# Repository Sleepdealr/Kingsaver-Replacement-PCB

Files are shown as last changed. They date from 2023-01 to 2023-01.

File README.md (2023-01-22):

# Kingsaver Replacement PCB

Replacement PCB for the Kingsaver

This has been prototyped and is confirmed working

<br />This work is licensed under a <a rel="license" href="http://creativecommons.org/licenses/by-nc-sa/4.0/">Creative Commons Attribution-NonCommercial-ShareAlike 4.0 Unported License</a>.

# Production

Production gerbers are zipped in the `Gerbers` folder, with JLC assembly files in the `jlcpcb/assembly` folder

You can get USB connectors off LCSC at <https://lcsc.com/product-detail/USB-Connectors_Jing-Extension-of-the-Electronic-Co-920-462A2021D10102_C46398.html>

Photo of proto:

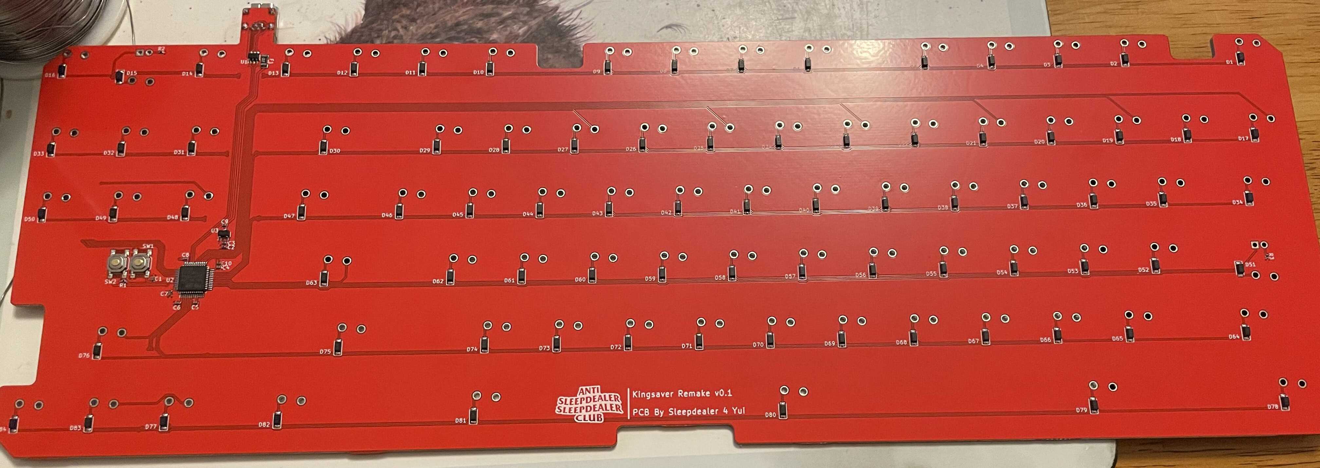
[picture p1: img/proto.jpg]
Photo of proto


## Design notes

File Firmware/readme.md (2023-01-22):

# sleepdealer/kingsaver_redo

sleepdealer/kingsaver_redo

*A short description of the keyboard/project*

* Keyboard Maintainer: [Sleepdealer](https://github.com/Sleepdealr)
* Hardware Supported: *The PCBs, controllers supported*
* Hardware Availability: *Links to where you can find this hardware*

Make example for this keyboard (after setting up your build environment):

    make sleepdealer/kingsaver_redo:default

Flashing example for this keyboard:

    make sleepdealer/kingsaver_redo:default:flash

See the [build environment setup](https://docs.qmk.fm/#/getting_started_build_tools) and the [make instructions](https://docs.qmk.fm/#/getting_started_make_guide) for more information. Brand new to QMK? Start with our [Complete Newbs Guide](https://docs.qmk.fm/#/newbs).

## Bootloader

Enter the bootloader in 3 ways:

* **Bootmagic reset**: Hold down the key at (0,0) in the matrix (usually the top left key or Escape) and plug in the keyboard
* **Physical reset button**: Briefly press the button on the back of the PCB - some may have pads you must short instead
* **Keycode in layout**: Press the key mapped to `RESET` if it is available

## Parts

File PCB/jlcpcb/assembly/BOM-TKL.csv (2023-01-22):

Comment | Designator | Footprint | LCSC
470 | R2,R3 | R_0402_1005Metric | C25117
10k | R1 | R_0402_1005Metric | C25744
USBLC6-2SC6 | U1 | SOT-23-6 | C2827654
100nF | C1,C4,C5,C6,C7,C8 | C_0402_1005Metric | C307331
RST | SW1,SW2 | SW_SPST_SKQG_WithoutStem | C318884
1uF | C10,C2,C3,C9 | C_0402_1005Metric | C52923
XC6206PxxxMR-Regulator_Linear | U3 | SOT-23 | C5446
500mA | F1 | Fuse_1206_3216Metric | C70076
STM32F072C8Tx | U2 | LQFP-48_7x7mm_P0.5mm | C80488
1n4148 | D1,D10,D11,D12,D13,D14,D15,D16,D17,D18,D19,D2,D20,D21,D22,D23,D24,D25,D26,D27,D28,D29,D3,D30,D31,D32,D33,D34,D35,D36,D37,D38,D39,D4,D40,D41,D42,D43,D44,D45,D46,D47,D48,D49,D5,D50,D51,D52,D53,D54,D55,D56,D57,D58,D59,D6,D60,D61,D62,D63,D64,D65,D66,D67,D68,D69,D7,D70,D71,D72,D73,D74,D75,D76,D77,D78,D79,D8,D80,D81,D82,D83,D84,D9 | D_SOD-123-EditSkilk | C81598

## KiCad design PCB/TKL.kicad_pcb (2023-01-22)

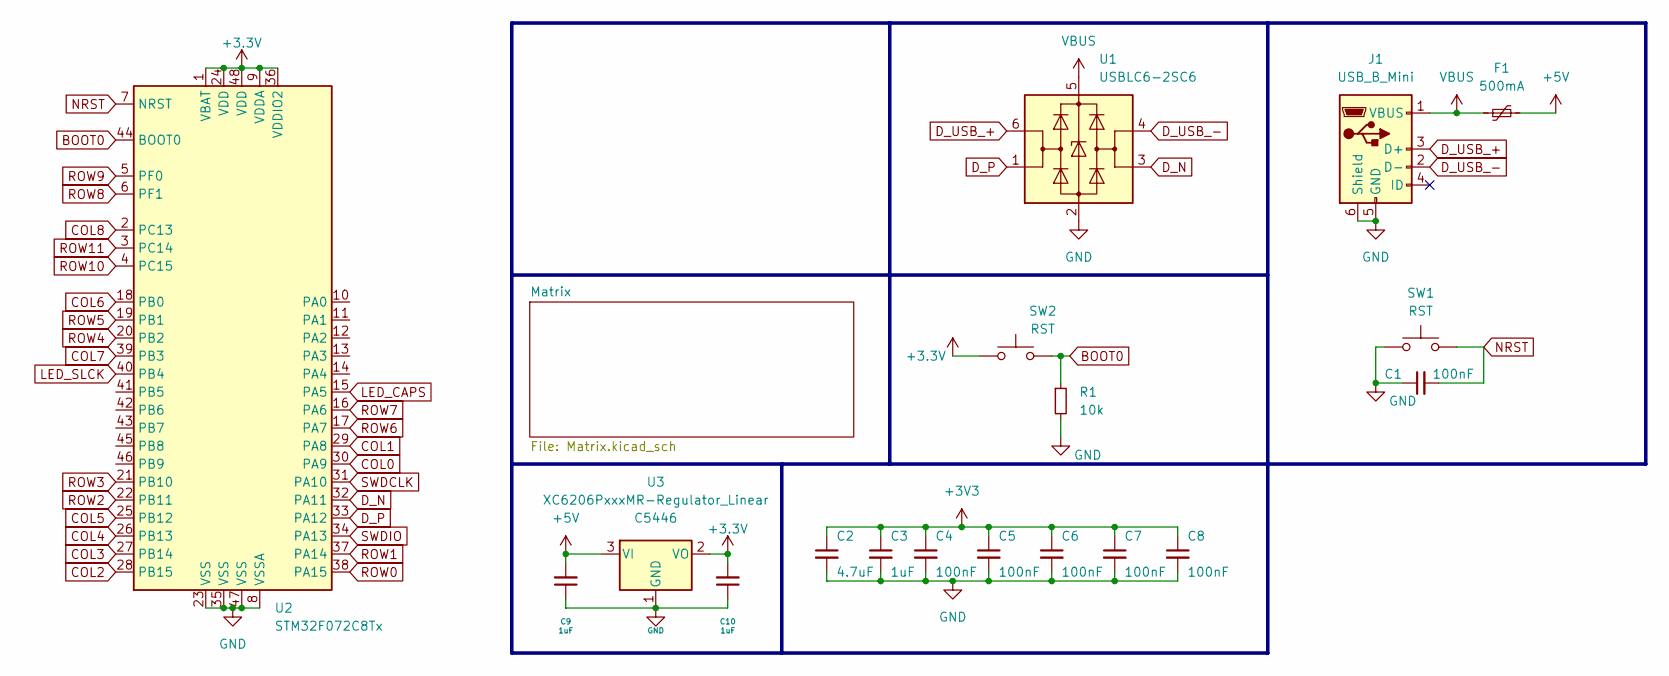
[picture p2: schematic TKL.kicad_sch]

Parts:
C1, C4, C5, C6, C7, C8: 100nF; C_0402_1005Metric; LCSC C307331
C2: 4.7uF; C_0402_1005Metric; LCSC C52923
C3, C9, C10: 1uF; C_0402_1005Metric; LCSC C52923
F1: 500mA; Fuse_1206_3216Metric
J1: USB_B_Mini; USB-Mini-B_ LCSC-C46398; LCSC C105424
R1: 10k; R_0402_1005Metric
SW1, SW2: RST; SW_SPST_SKQG_WithoutStem
U1: USBLC6-2SC6; SOT-23-6
U2: STM32F072C8Tx; LQFP-48_7x7mm_P0.5mm
U3: XC6206PxxxMR-Regulator_Linear; SOT-23; LCSC C5446

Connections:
+5V: C9.2, F1.2, U3.3 (VI)
BOOT0: R1.1, SW2.2, U2.44 (BOOT0)
COL0: U2.30 (PA9); also elsewhere on the board
COL1: U2.29 (PA8); also elsewhere on the board
COL2: U2.28 (PB15); also elsewhere on the board
COL3: U2.27 (PB14); also elsewhere on the board
COL4: U2.26 (PB13); also elsewhere on the board
COL5: U2.25 (PB12); also elsewhere on the board
COL6: U2.18 (PB0); also elsewhere on the board
COL7: U2.39 (PB3); also elsewhere on the board
COL8: U2.2 (PC13); also elsewhere on the board
D_N: U1.3 (I/O2), U2.32 (PA11)
D_P: U1.1 (I/O1), U2.33 (PA12)
D_USB_+: J1.3 (D+), U1.6 (I/O1)
D_USB_-: J1.2 (D-), U1.4 (I/O2)
GND: C1.1, C2.2, C3.2, C4.2, C5.2, C6.2, C7.2, C8.2, C9.1, C10.1, J1.5 (GND), J1.6 (Shield), R1.2, SW1.1, U1.2 (GND), U2.8 (VSSA), U2.23 (VSS), U2.35 (VSS), U2.47 (VSS), U3.1 (GND); also elsewhere on the board
LED_CAPS: U2.15 (PA5); also elsewhere on the board
LED_SLCK: U2.40 (PB4); also elsewhere on the board
NRST: C1.2, SW1.2, U2.7 (NRST)
ROW0: U2.38 (PA15); also elsewhere on the board
ROW1: U2.37 (PA14); also elsewhere on the board
ROW2: U2.22 (PB11); also elsewhere on the board
ROW3: U2.21 (PB10); also elsewhere on the board
ROW4: U2.20 (PB2); also elsewhere on the board
ROW5: U2.19 (PB1); also elsewhere on the board
ROW6: U2.17 (PA7); also elsewhere on the board
ROW7: U2.16 (PA6); also elsewhere on the board
ROW8: U2.6 (PF1); also elsewhere on the board
ROW9: U2.5 (PF0); also elsewhere on the board
ROW10: U2.4 (PC15); also elsewhere on the board
ROW11: U2.3 (PC14); also elsewhere on the board
SWDCLK: U2.31 (PA10)
SWDIO: U2.34 (PA13)
VBUS: F1.1, J1.1 (VBUS), U1.5 (VBUS)

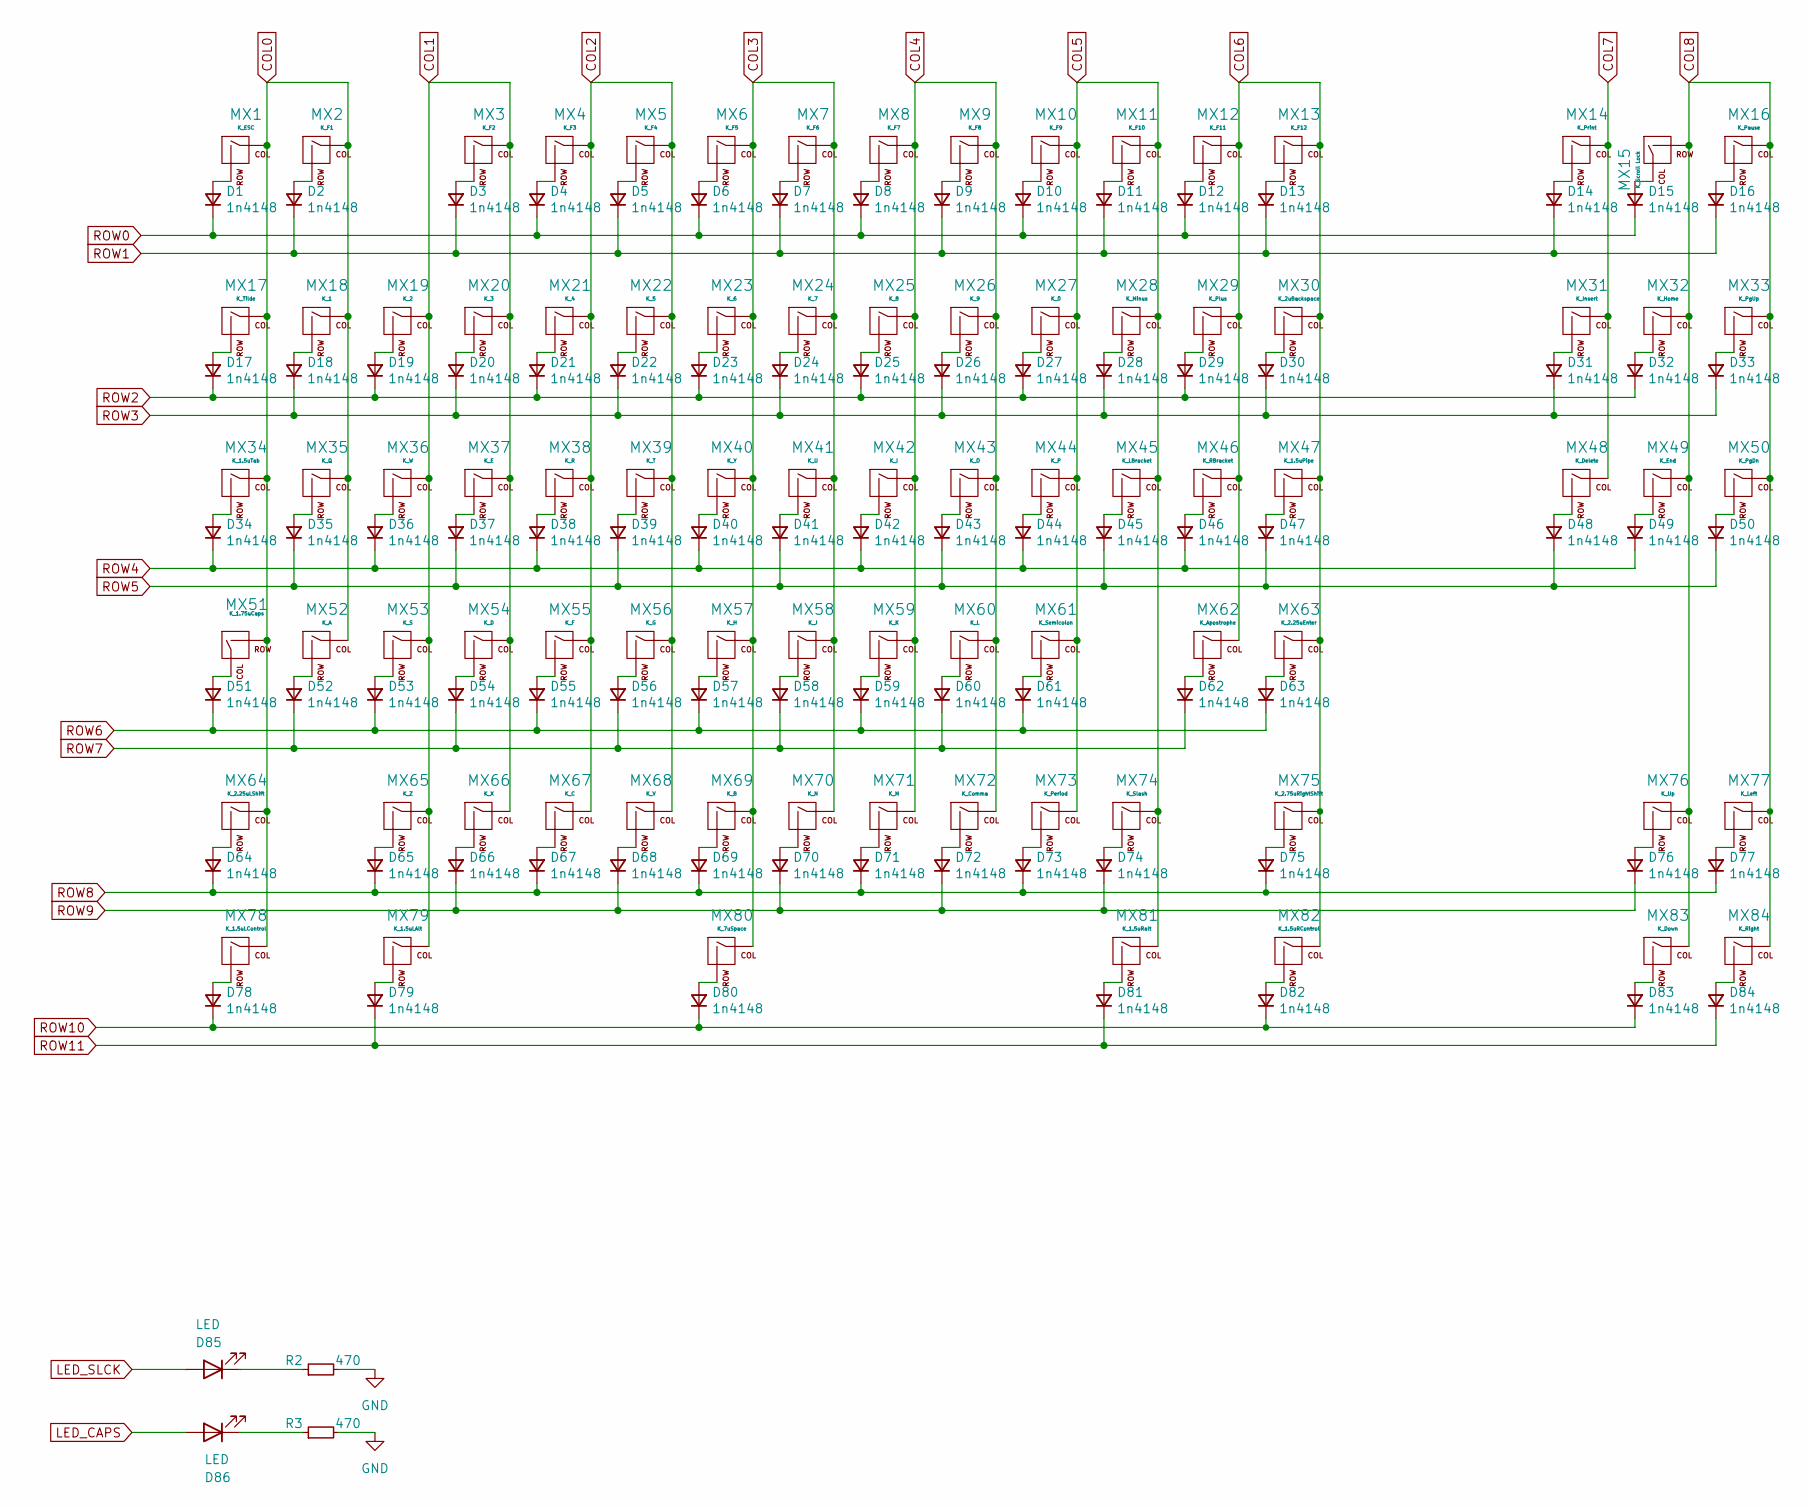
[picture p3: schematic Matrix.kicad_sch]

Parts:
D1, D2, D3, D4, D5, D6, D7, D8, D9, D10, D11, D12, D13, D14, D15, D16, D17, D18, D19, D20, D21, D22, D23, D24, D25, D26, D27, D28, D29, D30, D31, D32, D33, D34, D35, D36, D37, D38, D39, D40, D41, D42, D43, D44, D45, D46, D47, D48, D49, D50, D51, D52, D53, D54, D55, D56, D57, D58, D59, D60, D61, D62, D63, D64, D65, D66, D67, D68, D69, D70, D71, D72, D73, D74, D75, D76, D77, D78, D79, D80, D81, D82, D83, D84: 1n4148; D_SOD-123-EditSkilk; LCSC C81598
D85, D86: LED; ALPS-LEDONLY
MX1: K_ESC; SW_Alps_1u
MX2: K_F1; SW_Alps_1u
MX3: K_F2; SW_Alps_1u
MX4: K_F3; SW_Alps_1u
MX5: K_F4; SW_Alps_1u
MX6: K_F5; SW_Alps_1u
MX7: K_F6; SW_Alps_1u
MX8: K_F7; SW_Alps_1u
MX9: K_F8; SW_Alps_1u
MX10: K_F9; SW_Alps_1u
MX11: K_F10; SW_Alps_1u
MX12: K_F11; SW_Alps_1u
MX13: K_F12; SW_Alps_1u
MX14: K_Print; SW_Alps_1u
MX15: K_Scroll Lock; SW_Alps_1u
MX16: K_Pause; SW_Alps_1u
MX17: K_Tilde; SW_Alps_1u
MX18: K_1; SW_Alps_1u
MX19: K_2; SW_Alps_1u
MX20: K_3; SW_Alps_1u
MX21: K_4; SW_Alps_1u
MX22: K_5; SW_Alps_1u
MX23: K_6; SW_Alps_1u
MX24: K_7; SW_Alps_1u
MX25: K_8; SW_Alps_1u
MX26: K_9; SW_Alps_1u
MX27: K_0; SW_Alps_1u
MX28: K_Minus; SW_Alps_1u
MX29: K_Plus; SW_Alps_1u
MX30: K_2uBackspace; SW_Alps_1u
MX31: K_Insert; SW_Alps_1u
MX32: K_Home; SW_Alps_1u
MX33: K_PgUp; SW_Alps_1u
MX34: K_1.5uTab; SW_Alps_1.5u
MX35: K_Q; SW_Alps_1u
MX36: K_W; SW_Alps_1u
MX37: K_E; SW_Alps_1u
MX38: K_R; SW_Alps_1u
MX39: K_T; SW_Alps_1u
MX40: K_Y; SW_Alps_1u
MX41: K_U; SW_Alps_1u
MX42: K_I; SW_Alps_1u
MX43: K_O; SW_Alps_1u
MX44: K_P; SW_Alps_1u
MX45: K_LBracket; SW_Alps_1u
MX46: K_RBracket; SW_Alps_1u
MX47: K_1.5uPipe; SW_Alps_1.75u
MX48: K_Delete; SW_Alps_1u
MX49: K_End; SW_Alps_1u
MX50: K_PgDn; SW_Alps_1u
MX51: K_1.75uCaps; SW_Alps_1.75u
MX52: K_A; SW_Alps_1u
MX53: K_S; SW_Alps_1u
MX54: K_D; SW_Alps_1u
MX55: K_F; SW_Alps_1u
MX56: K_G; SW_Alps_1u
MX57: K_H; SW_Alps_1u
MX58: K_J; SW_Alps_1u
MX59: K_K; SW_Alps_1u
MX60: K_L; SW_Alps_1u
MX61: K_Semicolon; SW_Alps_1u
MX62: K_Apostrophe; SW_Alps_1u
MX63: K_2.25uEnter; SW_Alps_1u
MX64: K_2.25uLShift; SW_Alps_1u
MX65: K_Z; SW_Alps_1u
MX66: K_X; SW_Alps_1u
MX67: K_C; SW_Alps_1u
MX68: K_V; SW_Alps_1u
MX69: K_B; SW_Alps_1u
MX70: K_N; SW_Alps_1u
MX71: K_M; SW_Alps_1u
MX72: K_Comma; SW_Alps_1u
MX73: K_Period; SW_Alps_1u
MX74: K_Slash; SW_Alps_1u
MX75: K_2.75uRightShift; SW_Alps_1u
MX76: K_Up; SW_Alps_1u
MX77: K_Left; SW_Alps_1u
MX78: K_1.5uLControl; SW_Alps_1.5u
MX79: K_1.5uLAlt; SW_Alps_1.5u
MX80: K_7uSpace; SW_Alps_1u
MX81: K_1.5uRalt; SW_Alps_1.5u
MX82: K_1.5uRControl; SW_Alps_1.5u
MX83: K_Down; SW_Alps_1u
MX84: K_Right; SW_Alps_1u
R2, R3: 470; R_0402_1005Metric

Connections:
COL0: MX1.1 (COL), MX2.1 (COL), MX17.1 (COL), MX18.1 (COL), MX34.1 (COL), MX35.1 (COL), MX51.2 (ROW), MX52.1 (COL), MX64.1 (COL), MX78.1 (COL); also elsewhere on the board
COL1: MX3.1 (COL), MX19.1 (COL), MX20.1 (COL), MX36.1 (COL), MX37.1 (COL), MX53.1 (COL), MX54.1 (COL), MX65.1 (COL), MX66.1 (COL), MX79.1 (COL); also elsewhere on the board
COL2: MX4.1 (COL), MX5.1 (COL), MX21.1 (COL), MX22.1 (COL), MX38.1 (COL), MX39.1 (COL), MX55.1 (COL), MX56.1 (COL), MX67.1 (COL), MX68.1 (COL); also elsewhere on the board
COL3: MX6.1 (COL), MX7.1 (COL), MX23.1 (COL), MX24.1 (COL), MX40.1 (COL), MX41.1 (COL), MX57.1 (COL), MX58.1 (COL), MX69.1 (COL), MX70.1 (COL), MX80.1 (COL); also elsewhere on the board
COL4: MX8.1 (COL), MX9.1 (COL), MX25.1 (COL), MX26.1 (COL), MX42.1 (COL), MX43.1 (COL), MX59.1 (COL), MX60.1 (COL), MX71.1 (COL), MX72.1 (COL); also elsewhere on the board
COL5: MX10.1 (COL), MX11.1 (COL), MX27.1 (COL), MX28.1 (COL), MX44.1 (COL), MX45.1 (COL), MX61.1 (COL), MX73.1 (COL), MX74.1 (COL), MX81.1 (COL); also elsewhere on the board
COL6: MX12.1 (COL), MX13.1 (COL), MX29.1 (COL), MX30.1 (COL), MX46.1 (COL), MX47.1 (COL), MX62.1 (COL), MX63.1 (COL), MX75.1 (COL), MX82.1 (COL); also elsewhere on the board
COL7: MX14.1 (COL), MX31.1 (COL), MX48.1 (COL); also elsewhere on the board
COL8: MX15.2 (ROW), MX16.1 (COL), MX32.1 (COL), MX33.1 (COL), MX49.1 (COL), MX50.1 (COL), MX76.1 (COL), MX77.1 (COL), MX83.1 (COL), MX84.1 (COL); also elsewhere on the board
GND: R2.2, R3.2; also elsewhere on the board
LED_CAPS: D86.2 (A); also elsewhere on the board
LED_SLCK: D85.2 (A); also elsewhere on the board
unnamed: D1.2 (A), MX1.2 (ROW)
unnamed: D2.2 (A), MX2.2 (ROW)
unnamed: D3.2 (A), MX3.2 (ROW)
unnamed: D4.2 (A), MX4.2 (ROW)
unnamed: D5.2 (A), MX5.2 (ROW)
unnamed: D6.2 (A), MX6.2 (ROW)
unnamed: D7.2 (A), MX7.2 (ROW)
unnamed: D8.2 (A), MX8.2 (ROW)
unnamed: D9.2 (A), MX9.2 (ROW)
unnamed: D10.2 (A), MX10.2 (ROW)
unnamed: D11.2 (A), MX11.2 (ROW)
unnamed: D12.2 (A), MX12.2 (ROW)
unnamed: D13.2 (A), MX13.2 (ROW)
unnamed: D14.2 (A), MX14.2 (ROW)
unnamed: D15.2 (A), MX15.1 (COL)
unnamed: D16.2 (A), MX16.2 (ROW)
unnamed: D17.2 (A), MX17.2 (ROW)
unnamed: D18.2 (A), MX18.2 (ROW)
unnamed: D19.2 (A), MX19.2 (ROW)
unnamed: D20.2 (A), MX20.2 (ROW)
unnamed: D21.2 (A), MX21.2 (ROW)
unnamed: D22.2 (A), MX22.2 (ROW)
unnamed: D23.2 (A), MX23.2 (ROW)
unnamed: D24.2 (A), MX24.2 (ROW)
unnamed: D25.2 (A), MX25.2 (ROW)
unnamed: D26.2 (A), MX26.2 (ROW)
unnamed: D27.2 (A), MX27.2 (ROW)
unnamed: D28.2 (A), MX28.2 (ROW)
unnamed: D29.2 (A), MX29.2 (ROW)
unnamed: D30.2 (A), MX30.2 (ROW)
unnamed: D31.2 (A), MX31.2 (ROW)
unnamed: D32.2 (A), MX32.2 (ROW)
unnamed: D33.2 (A), MX33.2 (ROW)
unnamed: D34.2 (A), MX34.2 (ROW)
unnamed: D35.2 (A), MX35.2 (ROW)
unnamed: D36.2 (A), MX36.2 (ROW)
unnamed: D37.2 (A), MX37.2 (ROW)
unnamed: D38.2 (A), MX38.2 (ROW)
unnamed: D39.2 (A), MX39.2 (ROW)
unnamed: D40.2 (A), MX40.2 (ROW)
unnamed: D41.2 (A), MX41.2 (ROW)
unnamed: D42.2 (A), MX42.2 (ROW)
unnamed: D43.2 (A), MX43.2 (ROW)
unnamed: D44.2 (A), MX44.2 (ROW)
unnamed: D45.2 (A), MX45.2 (ROW)
unnamed: D46.2 (A), MX46.2 (ROW)
unnamed: D47.2 (A), MX47.2 (ROW)
unnamed: D48.2 (A), MX48.2 (ROW)
unnamed: D49.2 (A), MX49.2 (ROW)
unnamed: D50.2 (A), MX50.2 (ROW)
unnamed: D51.2 (A), MX51.1 (COL)
unnamed: D52.2 (A), MX52.2 (ROW)
unnamed: D53.2 (A), MX53.2 (ROW)
unnamed: D54.2 (A), MX54.2 (ROW)
unnamed: D55.2 (A), MX55.2 (ROW)
unnamed: D56.2 (A), MX56.2 (ROW)
unnamed: D57.2 (A), MX57.2 (ROW)
unnamed: D58.2 (A), MX58.2 (ROW)
unnamed: D59.2 (A), MX59.2 (ROW)
unnamed: D60.2 (A), MX60.2 (ROW)
unnamed: D61.2 (A), MX61.2 (ROW)
unnamed: D62.2 (A), MX62.2 (ROW)
unnamed: D63.2 (A), MX63.2 (ROW)
unnamed: D64.2 (A), MX64.2 (ROW)
unnamed: D65.2 (A), MX65.2 (ROW)
unnamed: D66.2 (A), MX66.2 (ROW)
unnamed: D67.2 (A), MX67.2 (ROW)
unnamed: D68.2 (A), MX68.2 (ROW)
unnamed: D69.2 (A), MX69.2 (ROW)
unnamed: D70.2 (A), MX70.2 (ROW)
unnamed: D71.2 (A), MX71.2 (ROW)
unnamed: D72.2 (A), MX72.2 (ROW)
unnamed: D73.2 (A), MX73.2 (ROW)
unnamed: D74.2 (A), MX74.2 (ROW)
unnamed: D75.2 (A), MX75.2 (ROW)
unnamed: D76.2 (A), MX76.2 (ROW)
unnamed: D77.2 (A), MX77.2 (ROW)
unnamed: D78.2 (A), MX78.2 (ROW)
unnamed: D79.2 (A), MX79.2 (ROW)
unnamed: D80.2 (A), MX80.2 (ROW)
unnamed: D81.2 (A), MX81.2 (ROW)
unnamed: D82.2 (A), MX82.2 (ROW)
unnamed: D83.2 (A), MX83.2 (ROW)
unnamed: D84.2 (A), MX84.2 (ROW)
unnamed: D85.1 (K), R2.1
unnamed: D86.1 (K), R3.1
ROW0: D1.1 (K), D4.1 (K), D6.1 (K), D8.1 (K), D10.1 (K), D12.1 (K), D15.1 (K); also elsewhere on the board
ROW1: D2.1 (K), D3.1 (K), D5.1 (K), D7.1 (K), D9.1 (K), D11.1 (K), D13.1 (K), D14.1 (K), D16.1 (K); also elsewhere on the board
ROW2: D17.1 (K), D19.1 (K), D21.1 (K), D23.1 (K), D25.1 (K), D27.1 (K), D29.1 (K), D32.1 (K); also elsewhere on the board
ROW3: D18.1 (K), D20.1 (K), D22.1 (K), D24.1 (K), D26.1 (K), D28.1 (K), D30.1 (K), D31.1 (K), D33.1 (K); also elsewhere on the board
ROW4: D34.1 (K), D36.1 (K), D38.1 (K), D40.1 (K), D42.1 (K), D44.1 (K), D46.1 (K), D49.1 (K); also elsewhere on the board
ROW5: D35.1 (K), D37.1 (K), D39.1 (K), D41.1 (K), D43.1 (K), D45.1 (K), D47.1 (K), D48.1 (K), D50.1 (K); also elsewhere on the board
ROW6: D51.1 (K), D53.1 (K), D55.1 (K), D57.1 (K), D59.1 (K), D61.1 (K), D63.1 (K); also elsewhere on the board
ROW7: D52.1 (K), D54.1 (K), D56.1 (K), D58.1 (K), D60.1 (K), D62.1 (K); also elsewhere on the board
ROW8: D64.1 (K), D65.1 (K), D67.1 (K), D69.1 (K), D71.1 (K), D73.1 (K), D75.1 (K), D77.1 (K); also elsewhere on the board
ROW9: D66.1 (K), D68.1 (K), D70.1 (K), D72.1 (K), D74.1 (K), D76.1 (K); also elsewhere on the board
ROW10: D78.1 (K), D80.1 (K), D82.1 (K), D83.1 (K); also elsewhere on the board
ROW11: D79.1 (K), D81.1 (K), D84.1 (K); also elsewhere on the board

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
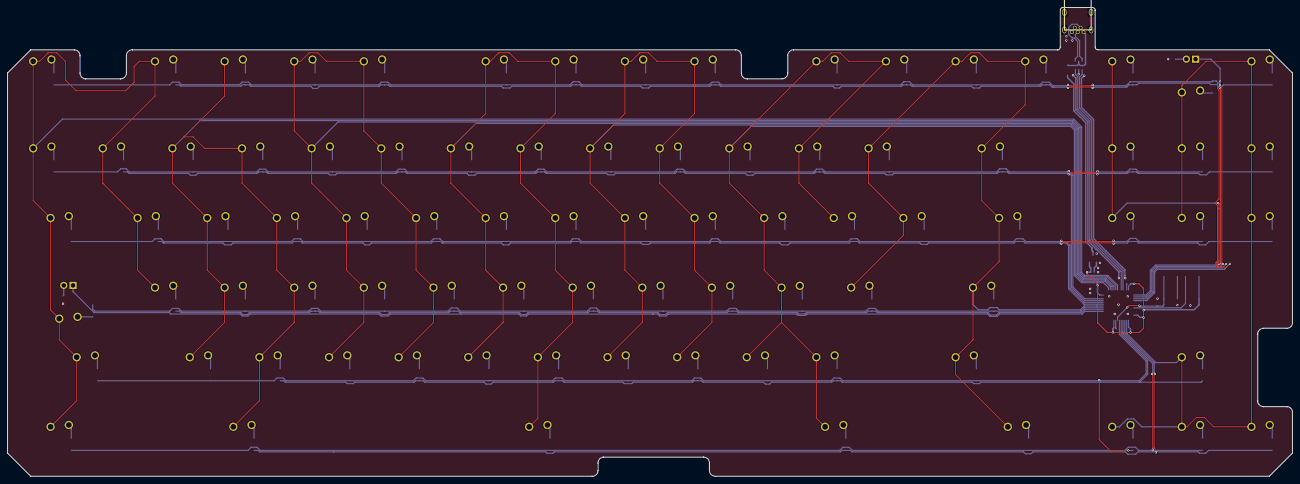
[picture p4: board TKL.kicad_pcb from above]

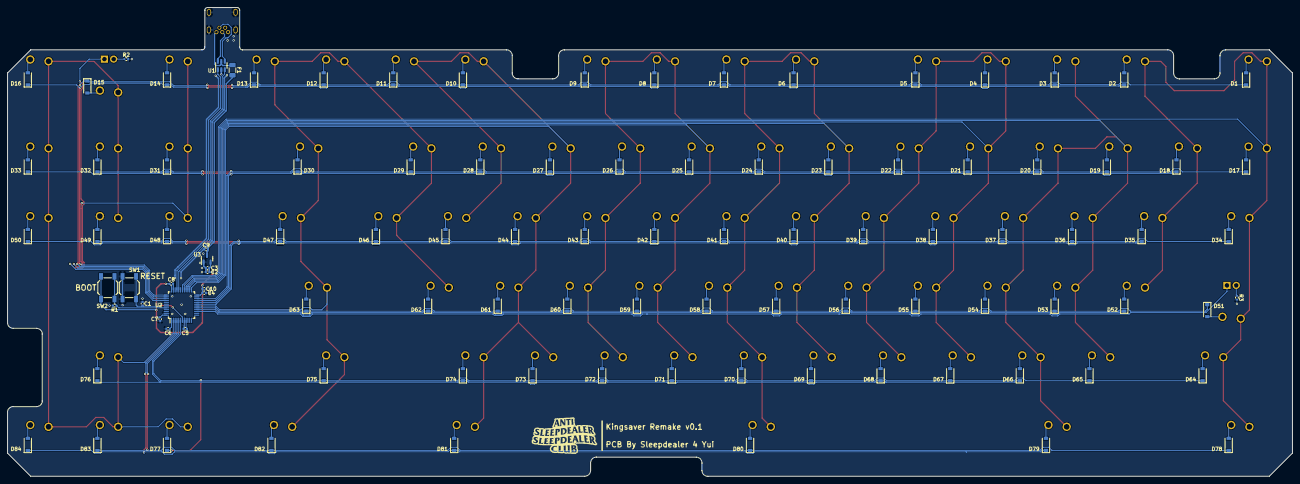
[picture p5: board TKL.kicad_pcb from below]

Board: 2 copper layers, 351.6 x 128.3 mm, 191 parts (104 on the bottom side), 119 nets.

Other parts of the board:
H1: MountingHole; assc_fixed
